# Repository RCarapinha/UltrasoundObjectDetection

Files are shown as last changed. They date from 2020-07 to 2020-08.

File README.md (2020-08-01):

# Ultrasound Object Detection

Project done in Electronic Laboratory in 1st year of Masters.

## Description

Implement an ultrasonic sensor in a robot, in order to make it detect obstacles that may arise along the way and make it deviate from them autonomously.

The project will be divided into several parts, starting with the assembly of the circuit on the white board, passing to the projection and design of the circuit in the Eagle software and the printing of the board is done to proceed with the soldering of the components.

## Job Done

The board designed was the following:

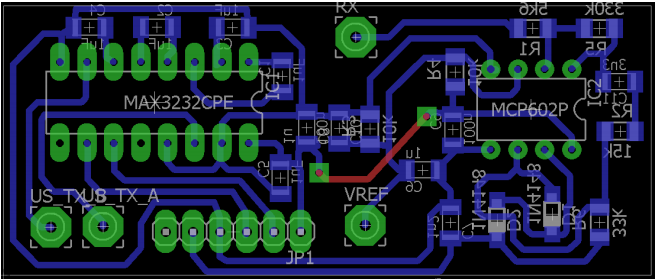
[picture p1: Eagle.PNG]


The final result was the following:

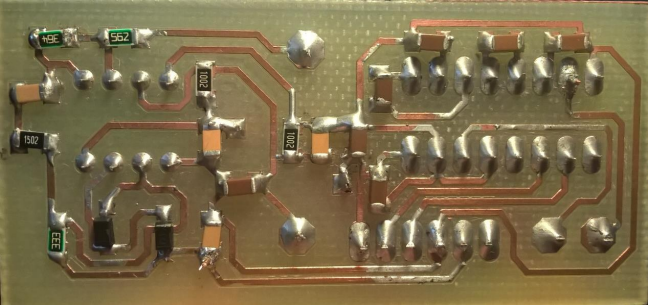
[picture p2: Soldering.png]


More info on the report.

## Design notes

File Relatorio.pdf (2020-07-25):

Miguel Pina, Paulo Pouseiro & Rui Carapinha – Deteção de obstáculos por ultrassons

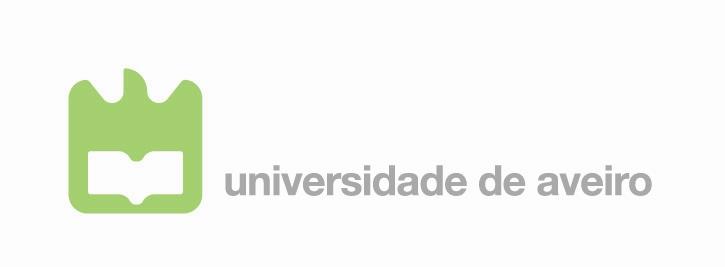
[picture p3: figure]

Departamento de eletrónica, telecomunicações e informática

Curso | 8204 - Mestrado Integrado e m Engenharia Eletrónica e Telecomunicações
Disciplina | 40331- Laboratórios em Eletrónica
Ano letivo | 2015/16

## Relatório

Projeto: Deteção de Obstáculos por Ultrassons

Autores:
79970 | Rui Filipe Santos Carapinha
80203
79886

Miguel Duarte Rocha Pina
Paulo Renato Ramos Pouseiro
Turma | TP7 | Grupo | 1
Data | 11/06/2016
Docente | Luís Nero Alves
Resumo: | Neste projeto, iremos equipar o robô DETI com um sensor de ultrassons, com o

objetivo de o fazer detetar obstáculos que possam surgir no caminho e fazê-lo

desviar-se de forma autónoma dos mesmos.

O projeto estará dividido em várias partes, sendo que começaremos pela montagem

do circuito na placa branca, passando à projeção e conceção do circuito no software

Eagle e, estando completa esta fase, é feita a impressão da placa para procedermos

à soldagem dos componentes.

Tendo a placa pronta, passa-se para a programação. Aqui, antes de serem feitos os programas que fazem o robô movimentar-se, é necessário demonstrar que temos

um sensor a funcionar. Feito isto, segue-se o desenvolvimento dos programas que

fazem o robô movimentar-se e desviar-se dos obstáculos detetados.

## Introdução

Os ultrassons são ondas sonoras (oscilações mecânicas que se propagam no ar) com

uma frequência superior à frequência máxima que o ouvido humano consegue detetar.

Este tipo de ondas tem diversas aplicações, entre elas a deteção de falhas em produtos

e estruturas, a limpeza, mistura e aceleração de processos químicos, ou até mesmo, quando

usado em baixa intensidade, na medicina, fisioterapia ou estética. No entanto, uma das

aplicações mais frequentes dos ultrassons é a medição da distância a um objeto, quer para

realizar a medida de um comprimento (por exemplo, as balanças que medem a altura para

determinar o índice de massa corporal) ou para detetar a presença de objetos ou obstáculos

(como é o caso dos sensores de estacionamento dos automóveis).

Este projeto irá centrar-se nesta última aplicação referida, sendo que iremos

desenvolver um sensor baseado em ultrassons para ligar ao robô DETI, permitindo a este robô

ser capaz de medir distâncias para se colocar a uma distância determinada de uma parede ou

qualquer outro obstáculo com que o robô se possa vir a deparar, ficando assim capaz de os

evitar.

De modo ao sensor de ultrassons conseguir medir distâncias ele faz uso do tempo que

demora um sinal enviado pelo transmissor a ser detetado num recetor.

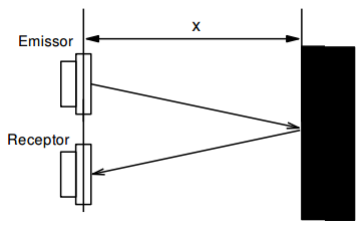
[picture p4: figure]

A variável x é calculada através de uma fórmula matemática de fácil dedução, pois, a

variável x é proporcional ao tempo que demora o sinal ao ser detetado no recetor e à velocidade com que este sinal se propaga, logo, a fórmula que nos fornece o valor de x é a

seguinte:

x =

1
2

∗ time ∗ velocity

Sendo que a variável velocity corresponde à velocidade do som que é dado de forma

aproximada pela seguinte equação:

c = 20.06 ∗ √temperature

Sendo que a variável temperatura corresponde à temperatura do ar em Kelvin.

Apresentado os ultrassons e como funciona o sensor, demonstraremos a aplicação

que fizemos do sensor de ultrassons e o o trabalho necessário para que isso fosse possível.

## Descrição do problema e dos objetivos

Ambos os temas para os projetos realizados este semestre consistem no

desenvolvimento e montagem de um circuito eletrónico simples, com vista a consolidar os

conhecimentos adquiridos pelos alunos e criar métodos de trabalho e organização e em que

a compreensão do funcionamento destes mesmos circuitos é obtida através de diferentes

elementos de informação (como o datasheet dos componentes, por exemplo). Para além

disto, teremos ainda uma componente de programação e uma componente de projeção e

conceção de circuitos eletrónicos com recurso ao software Eagle.

Para o tema do nosso projeto, pretendemos equipar o robô DETI com um sensor

baseado em ultrassons para deteção de obstáculos.

Para isso, teremos que conhecer o princípio de funcionamento de um sensor de

ultrassons e o princípio de desmodulação de sinal por deteção de envolvente. Teremos ainda

que programar um microcontrolador numa aplicação com interação com periféricos e

construir um sensor de ultrassons controlado pelo microcontrolador.

No fim do trabalho, iremos testar o funcionamento do nosso projeto, de modo a

verificar se os comportamentos que resultam da leitura do sensor e do uso da informação são

os esperados.

## Aparelhagem e Equipamento

Para a realização deste trabalho prático utilizou-se um osciloscópio digital, Tektronix

TDS1001B, robô DETI, uma placa branca, um gerador de sinal (Topward 8102), ferro de soldar,

2 pontas de prova, sensor de ultrassons (transmissor e recetor), solda, circuito integrado

MAX3232CPE, circuito integrado MC6022, 6 resistências (33kΩ, 15kΩ, 330kΩ, 5k6Ω e 2 de

10kΩ) e 11 condensadores (7 de 1µF, 1n2F, 3n3F e 2 de 100nF).

## Procedimento

Este miniprojecto foi realizado em 4 partes, sendo que a primeira incidia na realização

do circuito em placa branca, a segunda na realização de um esquemático e board do respetivo

circuito eletrónico no software Eagle, a terceira na soldadura dos respetivos componentes na

placa desenvolvida e uma quarta e última fase que incidia na realização do código na

linguagem de programação C++.

### 1. Circuito em Placa Branca

Para a realização desta fase do trabalho fez-se a montagem do circuito fornecido em

placa branca de modo a entender mais facilmente o seu funcionamento e de modo a, se

necessário, dimensionar uma resistência ou um condensador para obter o resultado

pretendido.

A montagem que se realizou foi a seguinte:

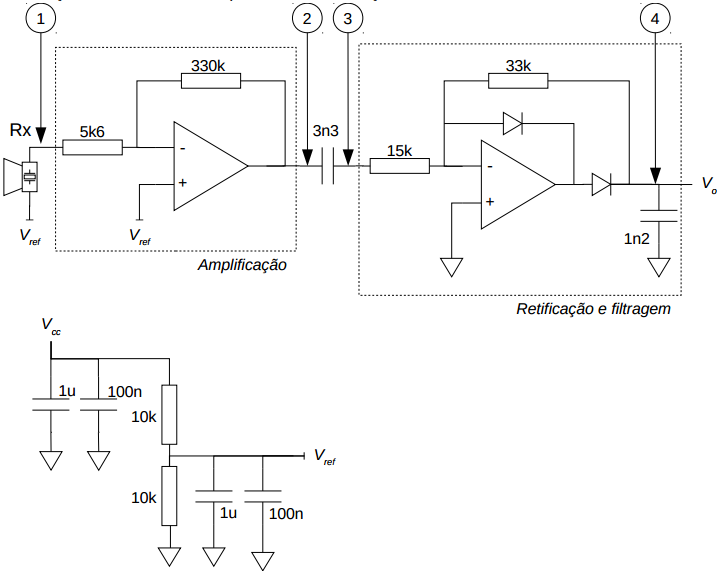
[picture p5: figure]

Após a montagem do circuito, fez uso das propriedades do gerador de sinal de modo

a simular o sensor de ultrassons (foi necessário realizar este passo pois os sensores de

ultrassons só ficaram disponíveis numa fase mais avançada do trabalho). Com isto,

entendeu-se como o circuito funcionava e não foi necessário dimensionar nenhuma

resistência nem nenhum condensador. Passou-se então à realização do circuito no

software Eagle.

### 2. Realização do esquemático e board no software Eagle

Realizado o circuito em placa branca, procedeu-se à realização do circuito no software

Eagle.

Primeiro foi necessário realizar o esquemático tendo como ponto de partida o ficheiro

disponibilizado pelos docentes. Este ficheiro já possuía a parte referente ao circuito de

transmissão, era apenas necessário realizar a parte referente ao circuito de receção.

O esquemático realizado foi o seguinte:

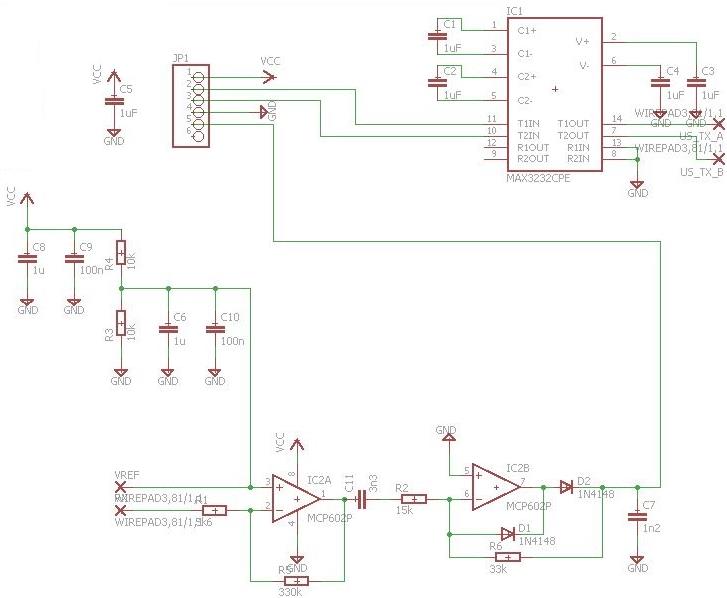
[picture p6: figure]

Após a realização do esquemático procedeu-se à realização da board, tendo o cuidado de não passar pistar entre os PAD’s de uma resistência, não passar mais de duas pistas por

baixo dos circuitos integrados, os ângulos das pistas serem sempre a 45º, de obter uma

board sem erros e de a realizar o mais pequena possível. Após isto, o board resultante foi

o seguinte:

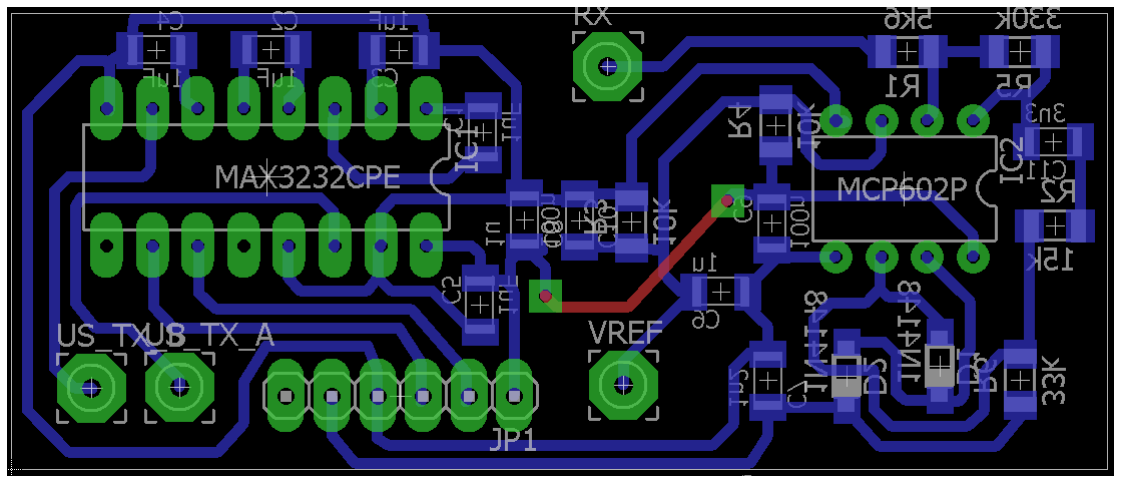
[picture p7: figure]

Depois da realização do esquemático e do board foi necessário esperar que o PCB fosse

desenvolvido para começar a soldar os componentes.

### 3. Soldagem dos componentes

Após obtermos o PCB realizado, procedeu-se à soldagem dos componentes. Para esta

parte foi necessário solda, um ferro de soldar e os respetivos componentes. Após a

soldagem a PCB obtido foi o seguinte:

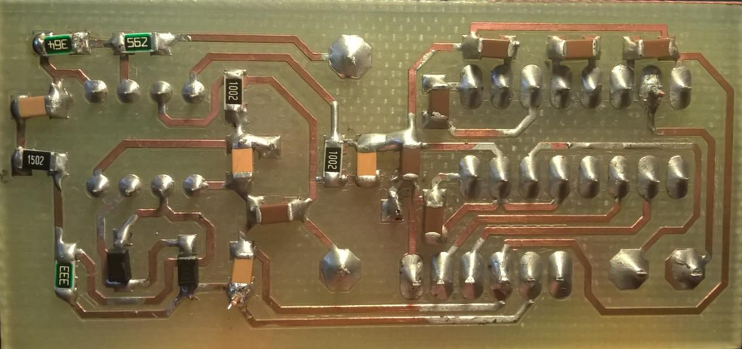
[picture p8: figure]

### 4. Realização do algoritmo em C++

Com o PCB desenvolvido foi necessário passar ao desenvolvimento do programa de

modo a atingir o objetivo principal de fazer o robô DETI desviar-se de obstáculos. De modo

a sabermos como programar em C++ realizou-se uma aula inteiramente dedicada a essa linguagem de programação. O código desenvolvido atua de acordo com a distância a que

o robô está a detetar um obstáculo.

## Testes de verificação do funcionamento do circuito

De modo a garantir que a placa estava bem realizada foi necessário possíveis causas

de curto-circuito (sendo que a placa foi limpa de modo a limpar todos os eventuais resíduos

que pudessem causar algo de não pretendido) e verificar se todos os componentes estavam

bem soldados ou não.

Após realizar isto procedeu-se a alguns testes com o auxílio do osciloscópio para se

verificar que os gráficos obtidos correspondiam com os pretendidos.

Os resultados obtidos foram os seguintes:

### 1. Após retificação e filtragem

a. Distância Curta

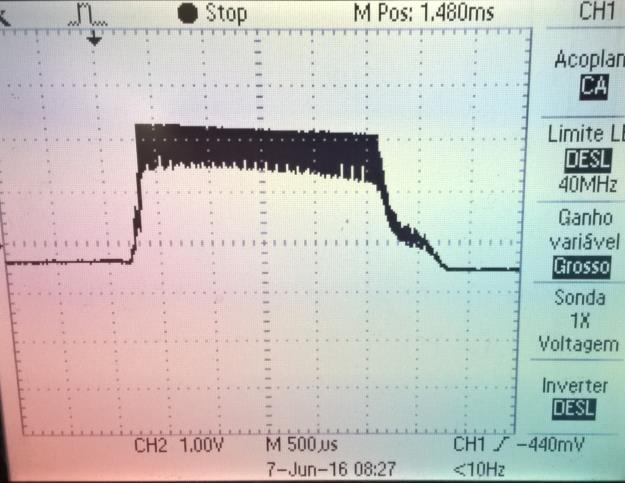
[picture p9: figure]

b. Distância Média

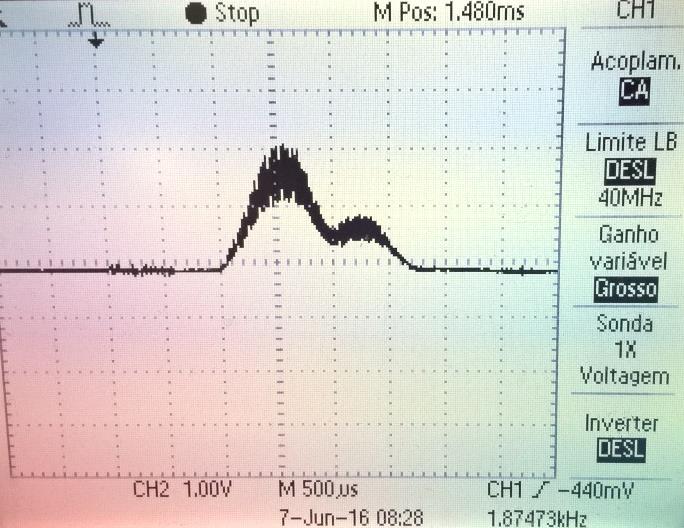
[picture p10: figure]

c. Distância Longa

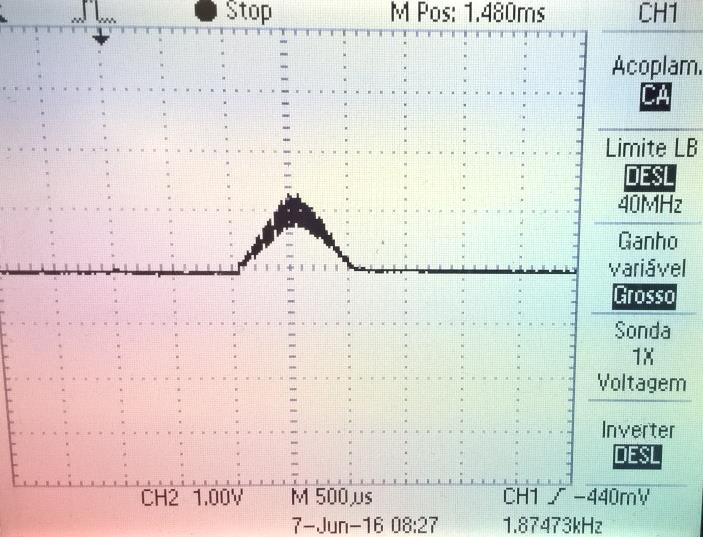
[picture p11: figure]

### 2. Antes da retificação e filtragem

a. Distância Curta

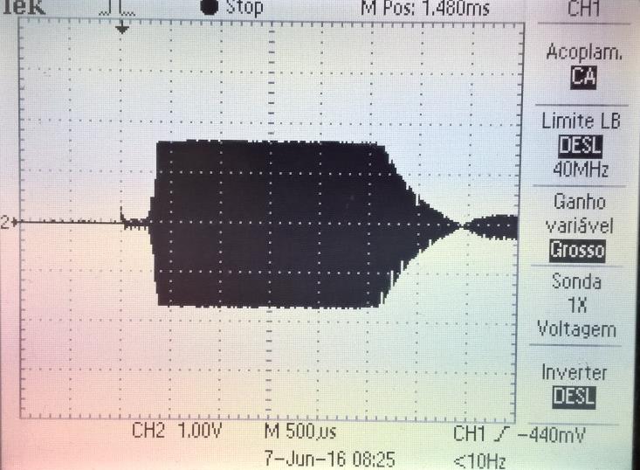
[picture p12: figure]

b. Distância Média

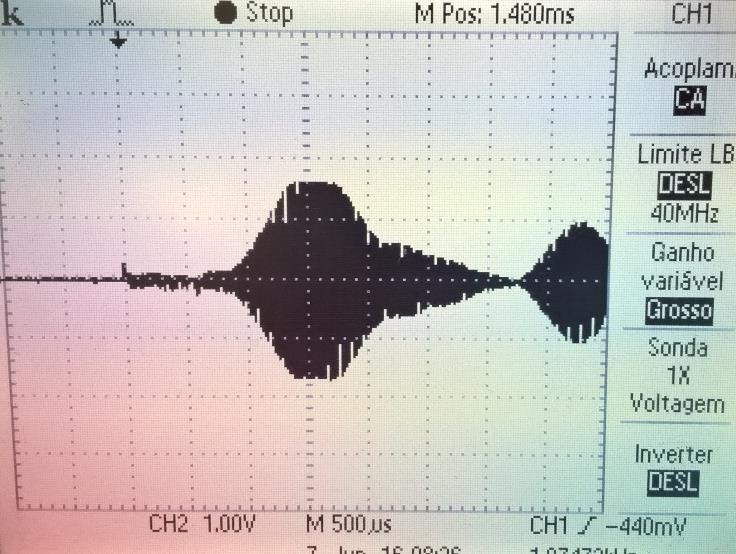
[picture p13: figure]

c. Distância Longa

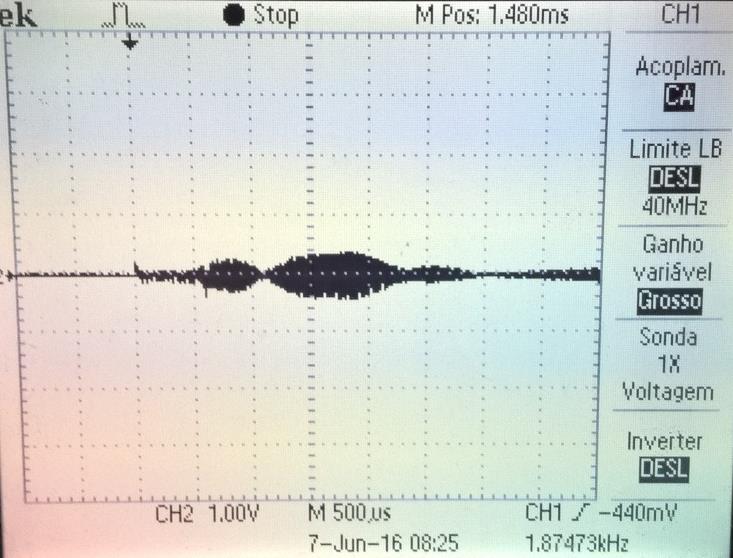
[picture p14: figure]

Podemos reparar que de facto o PCB funciona como esperado, quando a curtas

distâncias o valor medido no osciloscópio atinge o máximo da gama (3.3V) quando a grandes

distâncias o valor medido no osciloscópio é baixíssimo.

## Código

Os princípios do código que desenvolvemos são simples: emitir um sinal ultrassom, o

robô apercebe-se a distância a que se encontra dele e desvia-se caso necessário.

O código inicializa com a emissão do sinal ultrassom, utilizando uma das funções

presentes numa das bibliotecas utilizados neste projeto, a função uSound_burst(). Com esta

função gerou-se um pulso de 600 microssegundos de duração.

De seguida através da função in_analog() determinava-se o valor de tensão presente

no componente recetor. Esta tensão ia ser comparada com certo valor e caso fosse superior

ao valor pré-estabelecido, o robot iria virar para um dos lados (a escolha do lado era dado por

uma variável do tipo inteiro que era sempre incrementada e era o resultado do resto da

divisão por 2). Também foi implementado uma função que permitia ao robô estacionar após

ser premida o botão START. Caso contrário, o robô iria seguir o seu trajeto.

## Conclusão

Após a realização do trabalho, considerámos cumprido o objetivo geral estipulado, ou

seja, conseguiu-se equipar o robô do DETI com um sensor baseado em ultrassons que se

desvia de forma autónoma dos obstáculos que encontra no trajeto realizado.

## Referências

- [1] Guia de Sensor Ultrassons – 2º semestre – Mini Projeto – Deteção de obstáculos por ultrassons

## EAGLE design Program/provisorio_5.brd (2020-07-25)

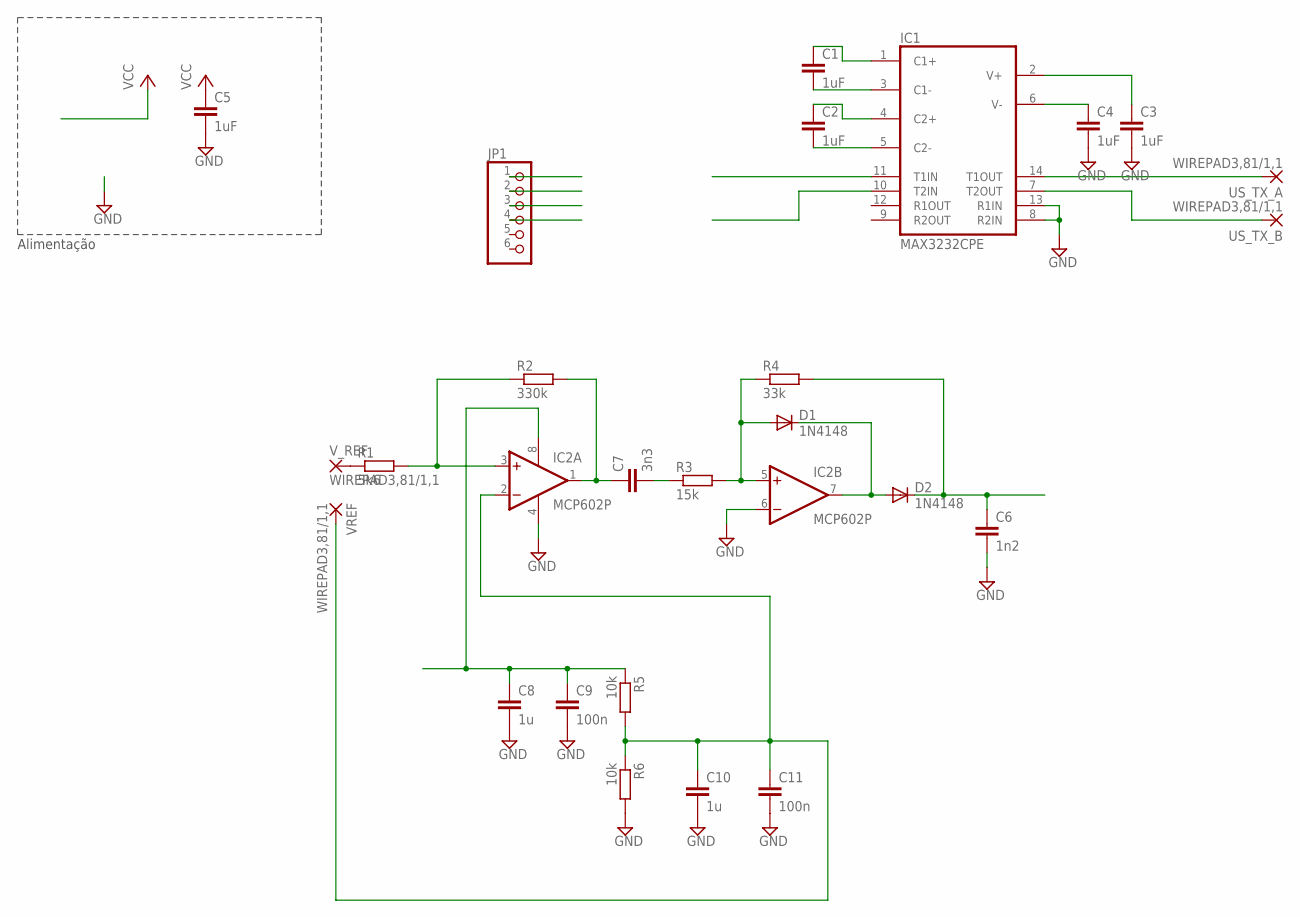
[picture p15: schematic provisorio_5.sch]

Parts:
C1, C2, C3, C4, C5: 1uF; C1206K
C6: 1n2; C1206K
C7: 3n3; C1206K
C8, C10: 1u; C1206K
C9, C11: 100n; C1206K
D1, D2: 1N4148; SOD123
IC1: MAX3232CPE; DIL16
IC2: MCP602P; DIL08
JP1: PINHD-1X6; 1X06
R1: 5k6; R1206
R2: 330k; R1206
R3: 15k; R1206
R4: 33k; R1206
R5, R6: 10k; R1206
US_TX_A: WIREPAD3,81/1,1; 3,81/1,1
US_TX_B: WIREPAD3,81/1,1; 3,81/1,1
VREF: WIREPAD3,81/1,1; 3,81/1,1
V_REF: WIREPAD3,81/1,1; 3,81/1,1

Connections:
DIGI1: C6.1, D2.C, IC1.11 (T1IN), JP1.2, R4.2
DIGI2: IC1.10 (T2IN), JP1.1
GND: C3.2, C4.2, C5.2, C6.2, C8.2, C9.2, C10.2, C11.2, IC1.8 (R2IN), IC1.13 (R1IN), IC1.15 (GND), IC2.4 (V-), IC2.6 (-IN), JP1.3, R6.2
unnamed: C3.1, IC1.2 (V+)
unnamed: C2.2, IC1.5 (C2-)
unnamed: C2.1, IC1.4 (C2+)
unnamed: C1.2, IC1.3 (C1-)
unnamed: C1.1, IC1.1 (C1+)
unnamed: C4.1, IC1.6 (V-)
unnamed: IC1.14 (T1OUT), US_TX_A.1
unnamed: IC1.7 (T2OUT), US_TX_B.1
unnamed: IC2.3 (+IN), R1.2, R2.1
unnamed: C7.1, IC2.1 (OUT), R2.2
unnamed: C7.2, R3.1
unnamed: D1.A, IC2.5 (+IN), R3.2, R4.1
unnamed: D1.C, D2.A, IC2.7 (OUT)
unnamed: R1.1, V_REF.1
unnamed: C10.1, C11.1, IC2.2 (-IN), R5.2, R6.1, VREF.1
VCC: C5.1, C8.1, C9.1, IC1.16 (VCC), IC2.8 (V+), JP1.4, R5.1

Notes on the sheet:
Alimentação

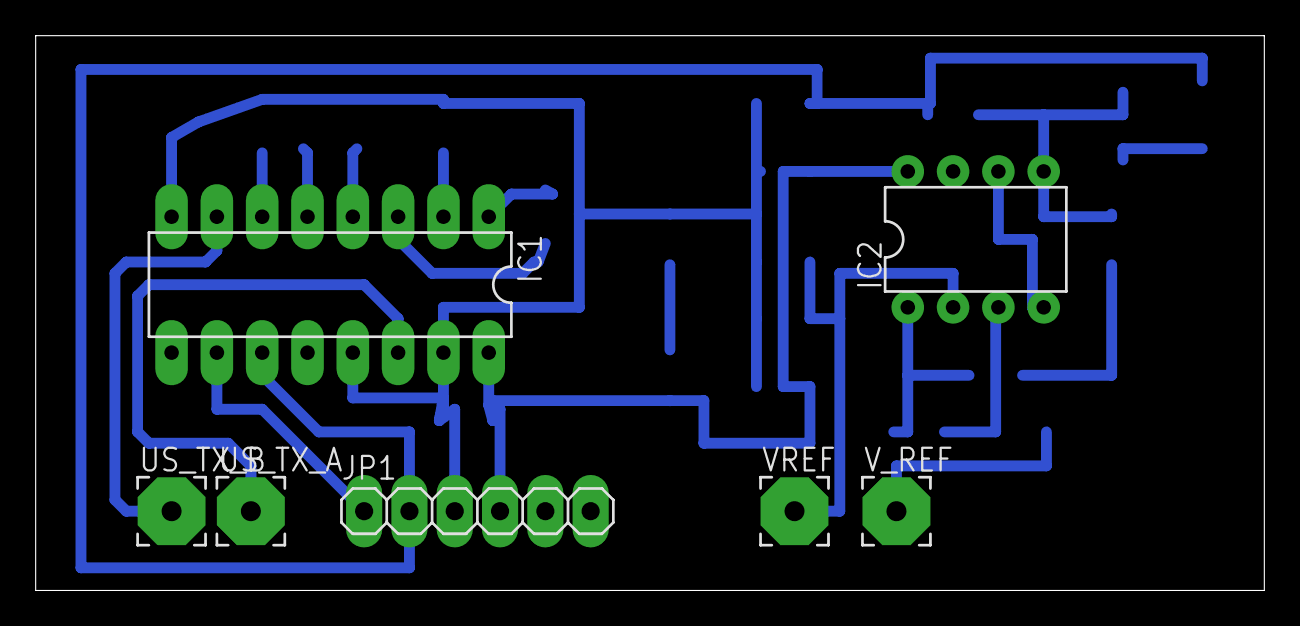
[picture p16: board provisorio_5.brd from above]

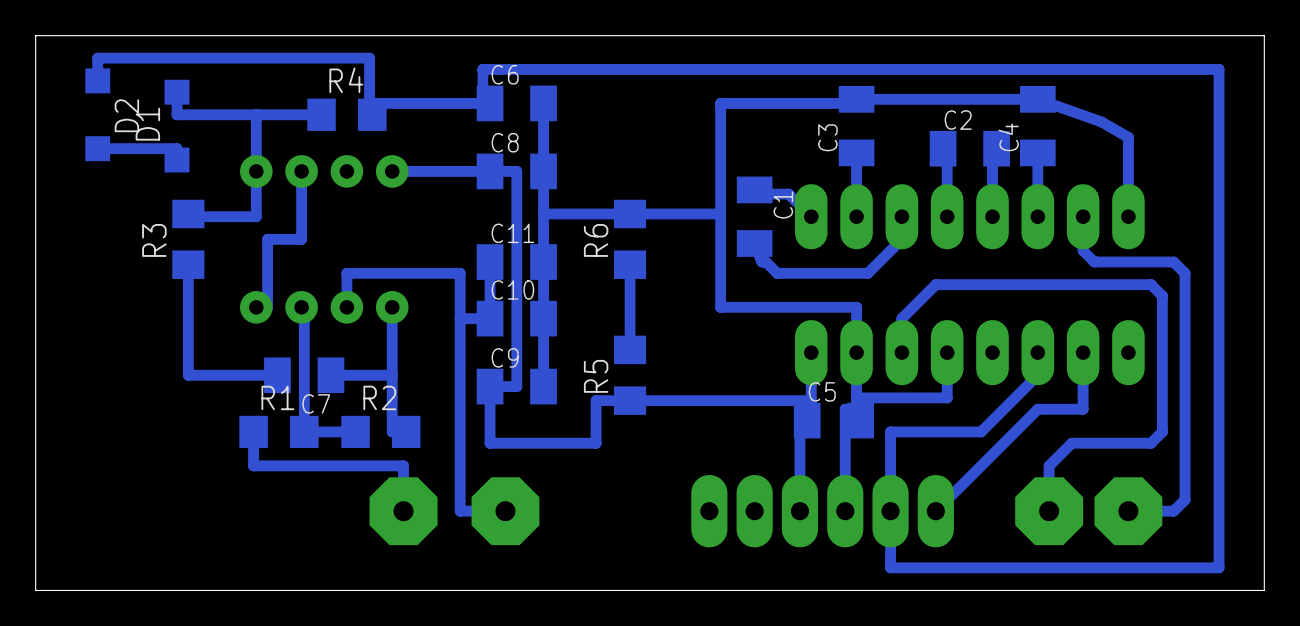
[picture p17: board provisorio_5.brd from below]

Board: 2 copper layers, 68.9 x 31.1 mm, 26 parts (19 on the bottom side), 19 nets.
